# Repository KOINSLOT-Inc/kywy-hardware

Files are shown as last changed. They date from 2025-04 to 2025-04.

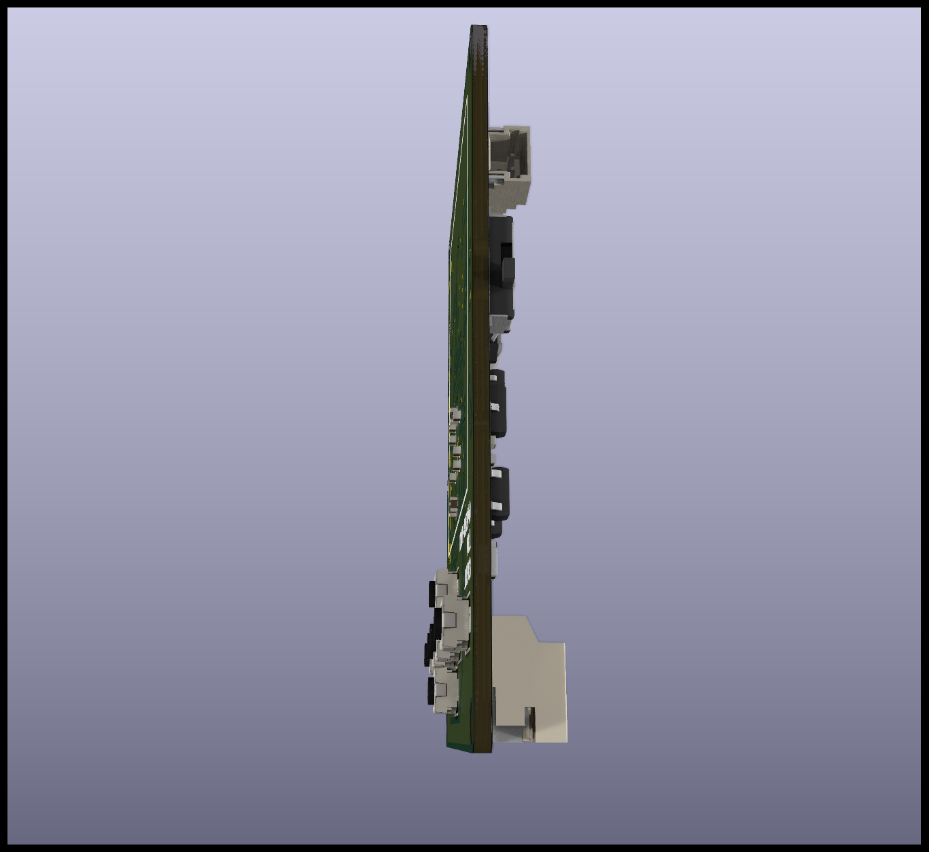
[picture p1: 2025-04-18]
PCB/Renders/Rotation/Kywy Micro Rotation 10.png

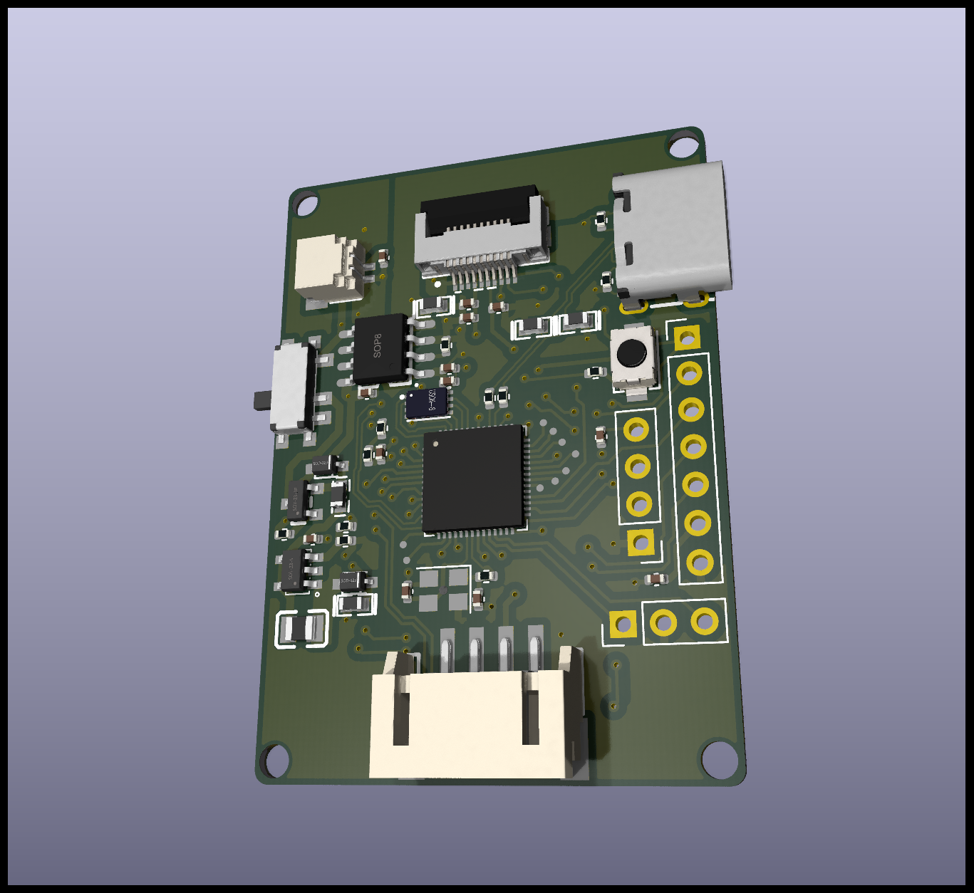
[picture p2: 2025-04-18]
PCB/Renders/Rotation/Kywy Micro Rotation 21.png

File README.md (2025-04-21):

<p align='center'>
  
  &nbsp;
  
  &nbsp;
  <a href="https://kywy.io/"><img alt="Website" src="https://img.shields.io/badge/KYWY.io-AAAAAA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" /></a>
  &nbsp;
  
</p>
<br />

# Kywy-Micro
 A handheld device for gaming
 
This repo contains all of the files you need to build a kywy pcb and 3d printed case

buy a kywy at [kywy.io](https://kywy.io)

Find our C++ and Rust libraries here: https://github.com/KOINSLOT-Inc

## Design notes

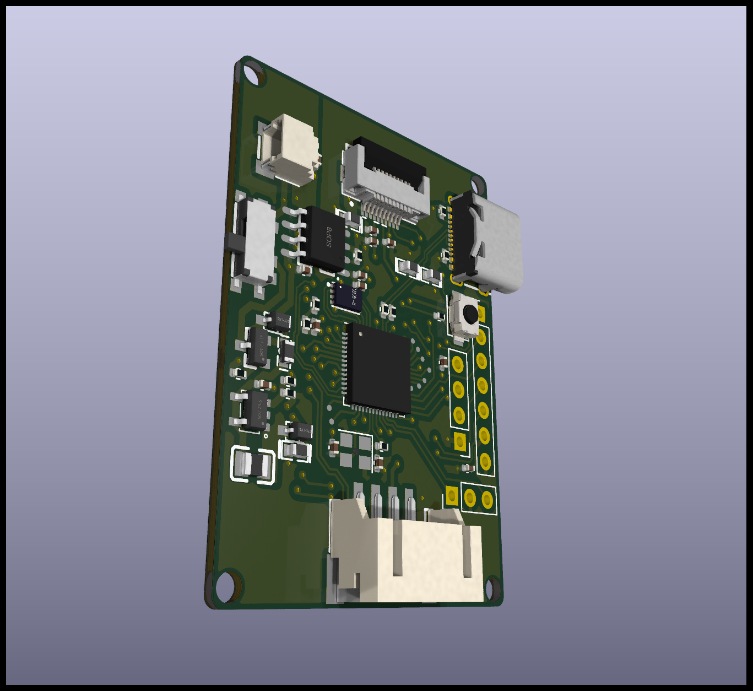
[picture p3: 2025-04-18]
PCB/Renders/Rotation/Kywy Micro Rotation 15.png

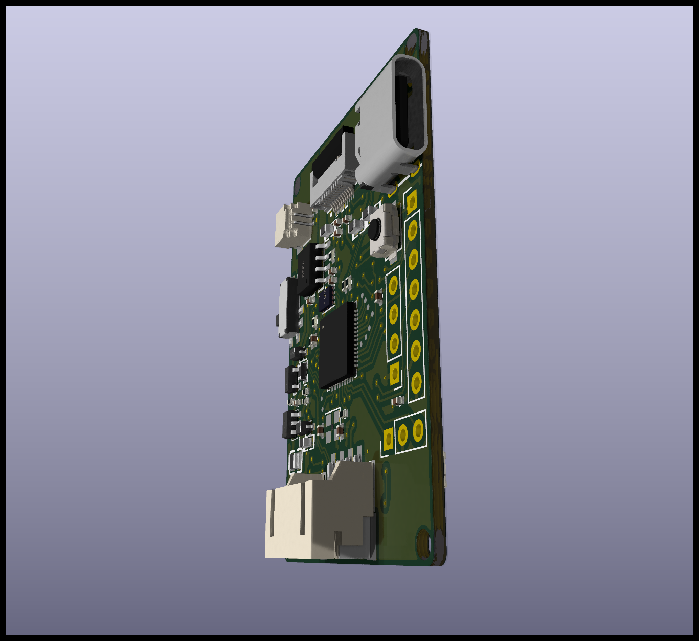
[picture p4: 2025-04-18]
PCB/Renders/Rotation/Kywy Micro Rotation 26.png

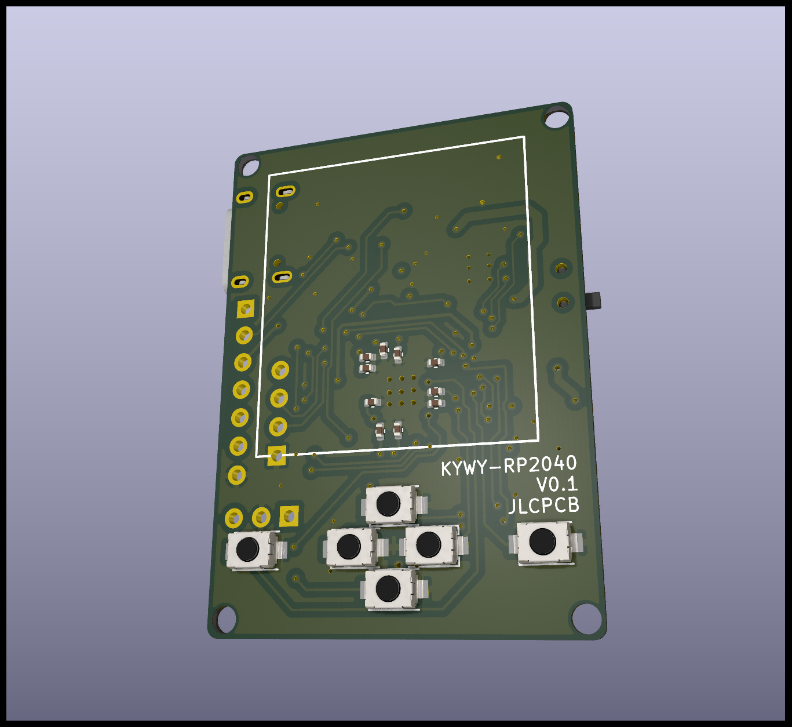
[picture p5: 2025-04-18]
PCB/Renders/Rotation/Kywy Micro Rotation 03.png

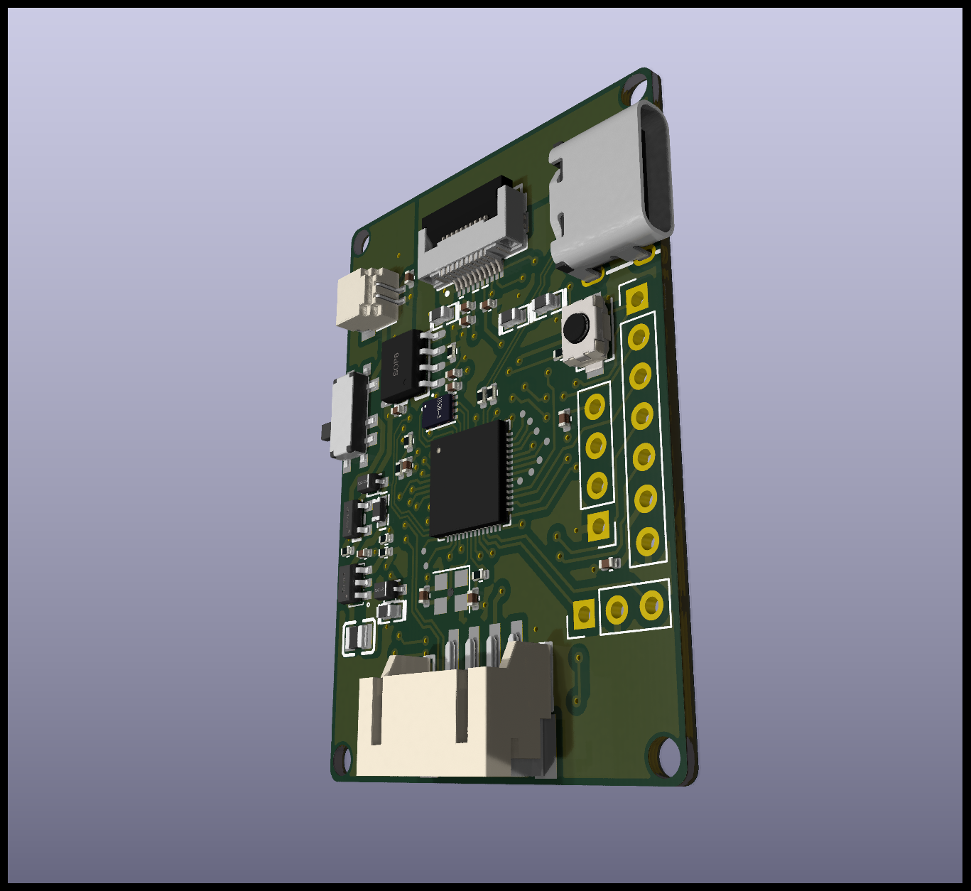
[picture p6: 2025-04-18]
PCB/Renders/Rotation/Kywy Micro Rotation 24.png

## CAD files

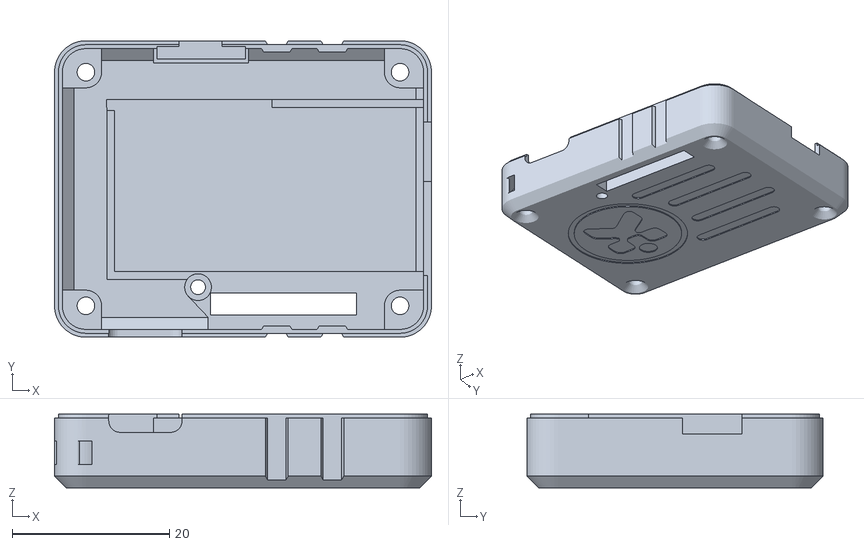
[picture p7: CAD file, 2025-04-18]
KYWY Case/Back.obj
48.0 x 37.8 x 9.40

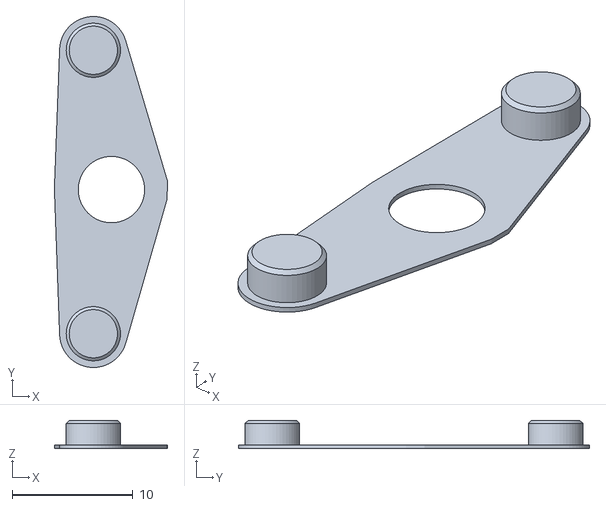
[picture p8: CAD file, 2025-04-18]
KYWY Case/Side Buttons.obj
9.39 x 29.1 x 2.35

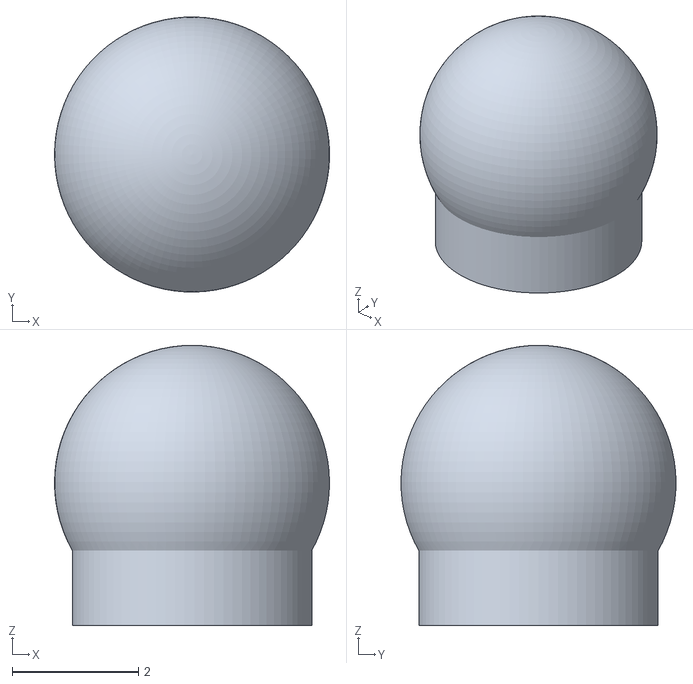
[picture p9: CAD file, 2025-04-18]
KYWY Case/Joystick.obj
4.35 x 4.35 x 4.44

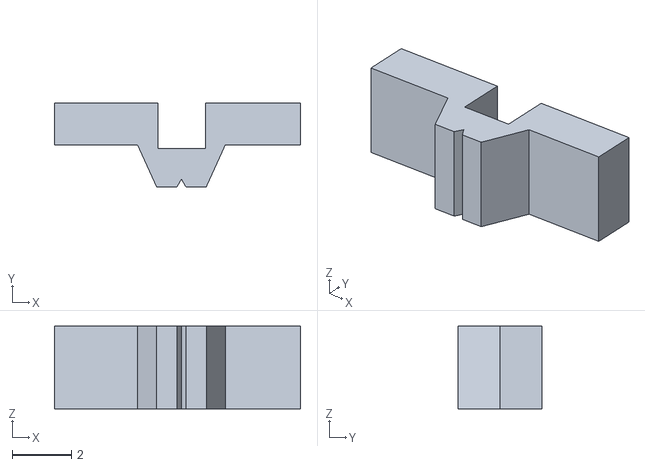
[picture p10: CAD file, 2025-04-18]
KYWY Case/Power Slider.obj
8.30 x 2.82 x 2.80

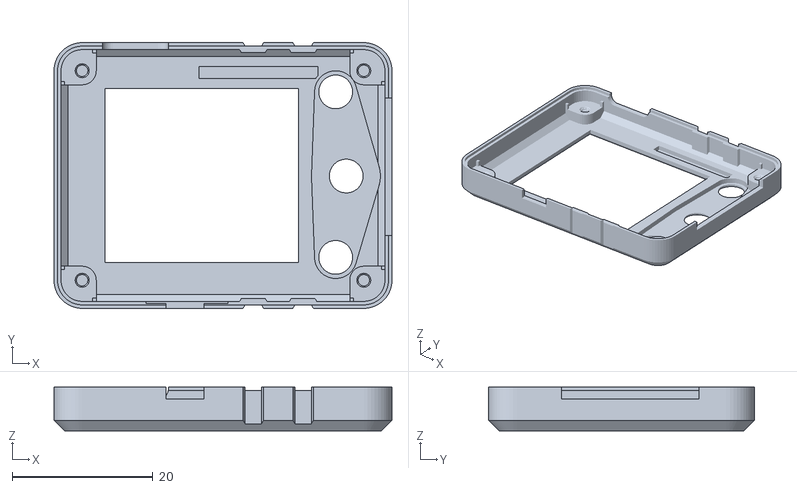
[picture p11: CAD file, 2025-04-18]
KYWY Case/Front.obj
48.0 x 37.8 x 6.20

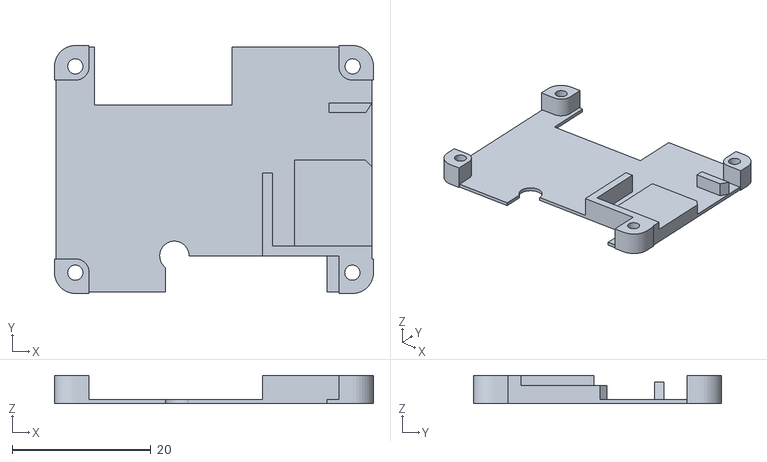
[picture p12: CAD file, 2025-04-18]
KYWY Case/Separator.obj
46.0 x 35.8 x 4.10

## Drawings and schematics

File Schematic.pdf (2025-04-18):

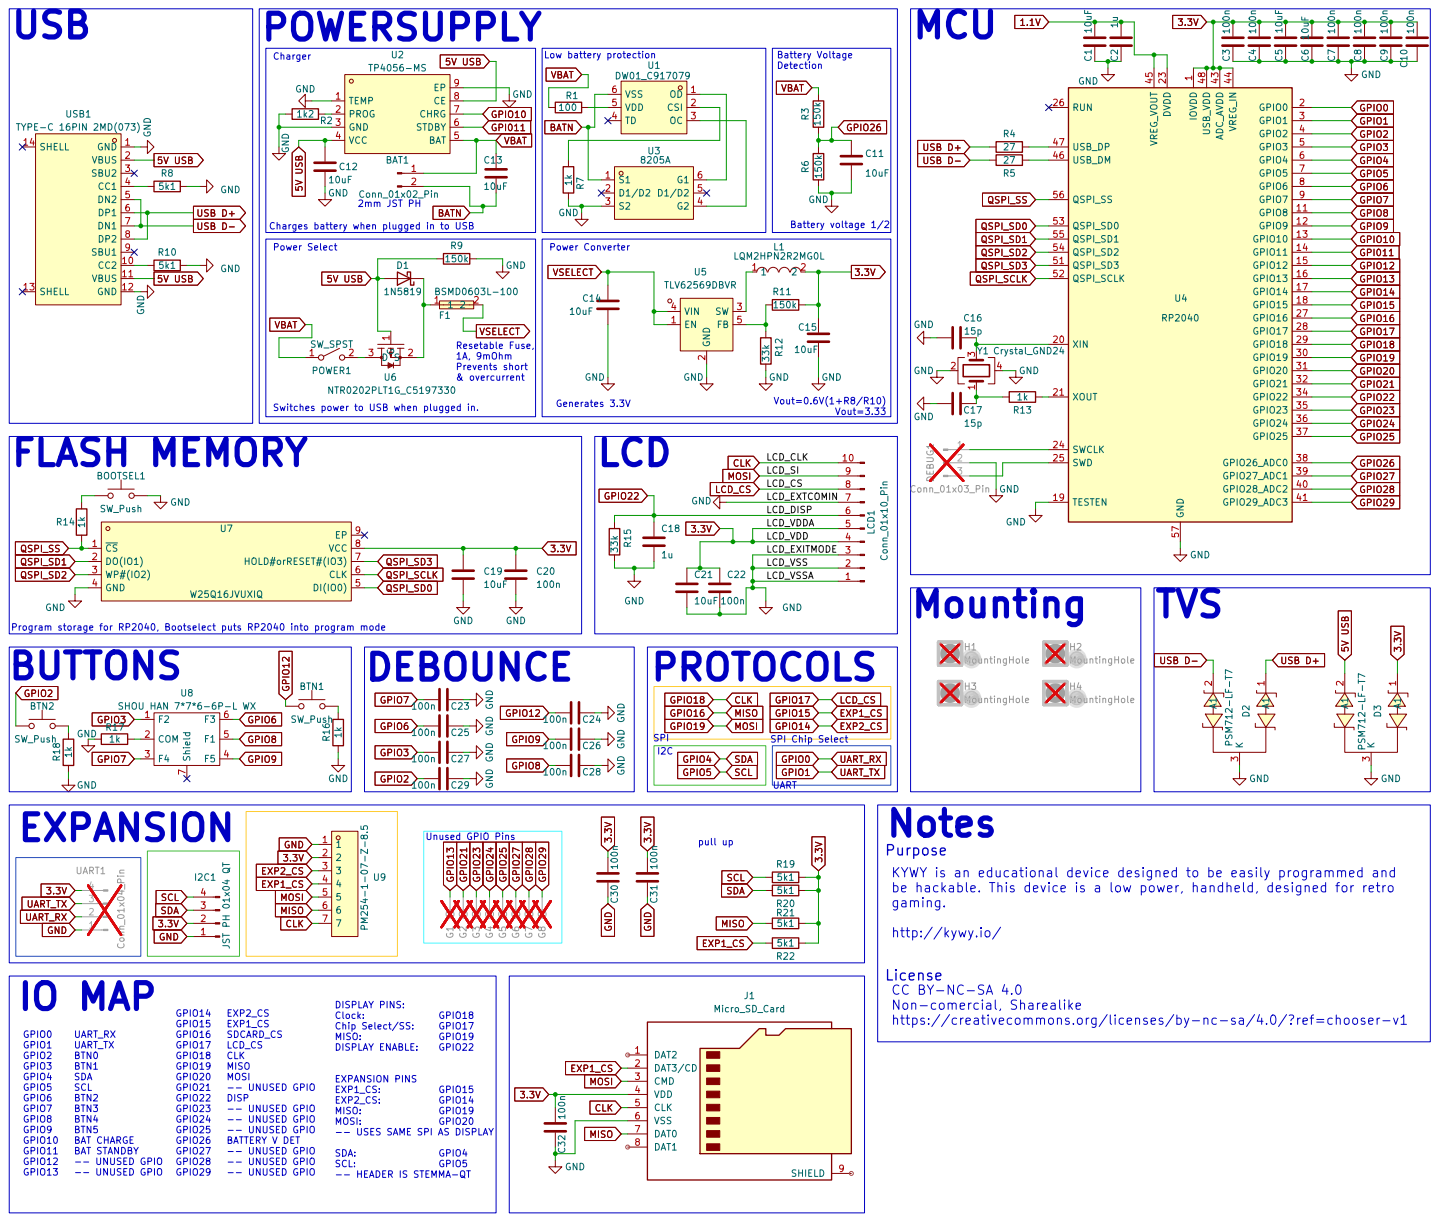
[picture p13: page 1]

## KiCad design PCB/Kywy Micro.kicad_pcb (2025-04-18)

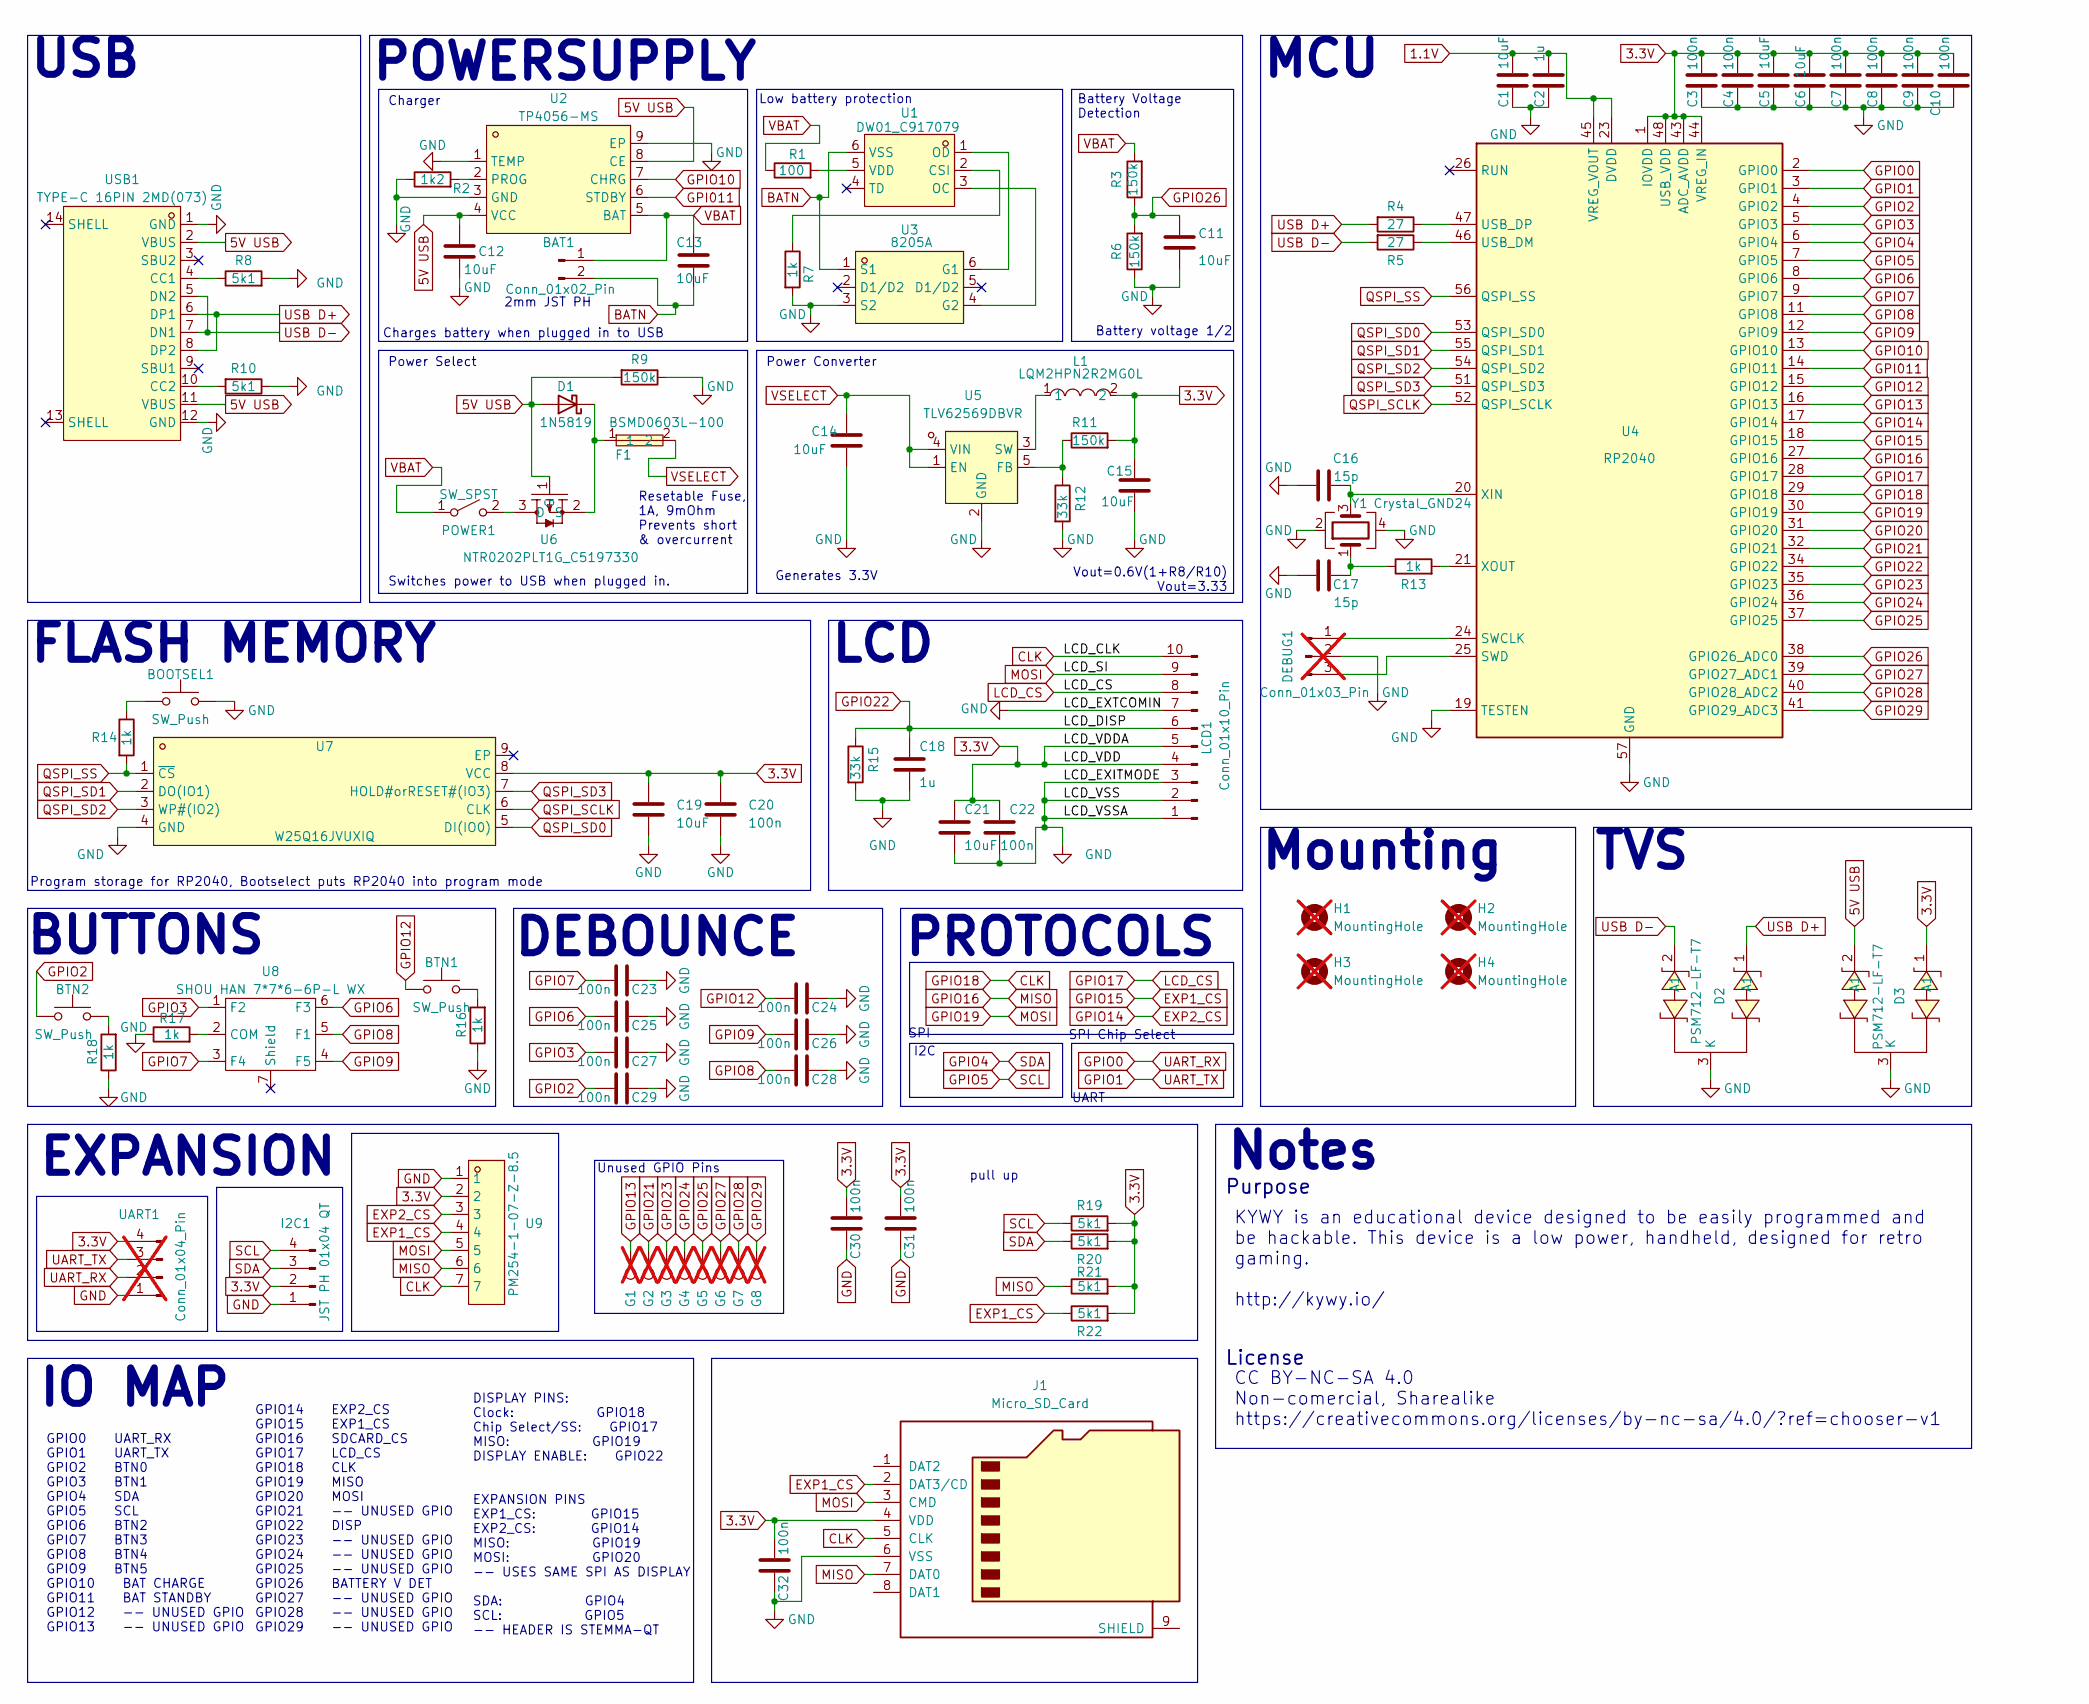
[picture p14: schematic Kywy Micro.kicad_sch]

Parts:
BAT1: Conn_01x02_Pin; CONN-TH_2P-P2.00_HX-2.0MM-2P-ZZ; JLCPCB Part #（optional） C5368724
BOOTSEL1: SW_Push; SW-SMD_L3.9-W3.0-P4.45; JLCPCB Part #（optional） C720477
BTN1, BTN2: SW_Push; SW-SMD_L3.9-W3.0-P4.45; JLCPCB Part #（optional） C720477
C1, C5, C6, C11, C12, C13, C14, C15, C19, C21: 10uF; C_0402_1005Metric; JLCPCB Part #（optional） C15525
C2, C18: 1u; C_0402_1005Metric; JLCPCB Part #（optional） C52923
C3, C4, C7, C8, C9, C10, C20, C22, C23, C24, C25, C26, C27, C28, C29, C30, C31, C32: 100n; C_0402_1005Metric; JLCPCB Part #（optional） C1525
C16, C17: 15p; C_0402_1005Metric; JLCPCB Part #（optional） C1548
D1: 1N5819; SOD-323_L1.8-W1.3-LS2.5-RD; JLCPCB Part #（optional） C191023
D2, D3: PSM712-LF-T7; SOT-23-3_L3.0-W1.7-P0.95-LS2.9-BR; LCSC Part C32677
DEBUG1: Conn_01x03_Pin; PinHeader_1x03_P2.54mm_Vertical; JLCPCB Part #（optional） DNP; not fitted
F1: BSMD0603L-100; F0603; JLCPCB Part #（optional） C2757929
G1, G2, G3, G4, G5, G6, G7, G8: TestPoint; Small Test Pad; JLCPCB Part #（optional） DNP; not fitted
H1, H2, H3, H4: MountingHole; MountingHole_2.2mm_M2; JLCPCB Part #（optional） DNP; not fitted
I2C1: JST PH 01x04 QT; CONN-SMD_4P-P1.00_MEGASTAR_ZX-SH1.0-4PWT; JLCPCB Part #（optional） C7430446
J1: Micro_SD_Card; TF-SMD_TF-123-ARP9H15; JLCPCB Part #（optional） C2982547
L1: LQM2HPN2R2MG0L; L1008; LCSC Part C86092
LCD1: Conn_01x10_Pin; FPC-SMD_P0.5-10P_FGS-XJ-H2.0; JLCPCB Part #（optional） C262659
POWER1: SW_SPST; SW-SMD_3P-P1.50_L2.7-W6.6; JLCPCB Part #（optional） C963206
R1: 100; R_0402_1005Metric; JLCPCB Part #（optional） C144045
R2: 1k2; R_0402_1005Metric; JLCPCB Part #（optional） C25862
R3, R6, R9, R11: 150k; R_0402_1005Metric; JLCPCB Part #（optional） C25755
R4, R5: 27; R_0402_1005Metric; JLCPCB Part #（optional） C25100
R7, R13, R14, R16, R17, R18: 1k; R_0402_1005Metric; JLCPCB Part #（optional） C11702
R8, R10, R19, R20, R21, R22: 5k1; R_0402_1005Metric; JLCPCB Part #（optional） C25905
R12, R15: 33k; R_0402_1005Metric; JLCPCB Part #（optional） C25779
U1: DW01_C917079; SOT-23-6_L2.9-W1.6-P0.95-LS2.8-BL; LCSC Part C917079
U2: TP4056-MS; SOP-8_L4.9-W3.9-P1.27-LS6.0-TL-EP; JLCPCB Part #（optional） C7473158
U3: 8205A; SOT-23-6_L2.9-W1.6-P0.95-LS2.8-BR; LCSC Part C2762931
U4: RP2040; QFN-56-1EP_7x7mm_P0.4mm_EP3.2x3.2mm; JLCPCB Part #（optional） C2040
U5: TLV62569DBVR; SOT-23-5_L3.0-W1.7-P0.95-LS2.8-BR; LCSC Part C141836
U6: NTR0202PLT1G_C5197330; SOT-23_L2.9-W1.3-P1.90-LS2.4-BR; JLCPCB Part #（optional） C5224173
U7: W25Q16JVUXIQ; USON-8_L3.0-W2.0-P0.50-BL-EP; JLCPCB Part #（optional） C2843335
U8: SHOU HAN 7*7*6-6P-L WX; SW-SMD_6P-L7.0-W7.0-P1.40-LS7.4; JLCPCB Part #（optional） C2858288
U9: PM254-1-07-Z-8.5; HDR-TH_7P-P2.54-V-F; LCSC Part C2897370
UART1: Conn_01x04_Pin; PinHeader_1x04_P2.54mm_Vertical; JLCPCB Part #（optional） DNP; not fitted
USB1: TYPE-C 16PIN 2MD(073); USB-C-SMD_TYPE-C-6PIN-2MD-073; JLCPCB Part #（optional） C2765186
Y1: Crystal_GND24; CRYSTAL-SMD_4P-L3.2-W2.5-BL; JLCPCB Part #（optional） C9002

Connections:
1.1V: C1.2, C2.2, U4.23 (DVDD), U4.45 (VREG_VOUT), U4.50 (DVDD)
3.3V: C3.2, C4.2, C5.2, C6.2, C7.2, C8.2, C9.2, C10.2, C15.1, C19.1, C20.1, C21.1, C22.1, C30.2, C31.2, C32.2, D3.1 (A1), I2C1.2, J1.4 (VDD), L1.2, LCD1.4, LCD1.5, R11.2, R19.2, R20.2, R21.2, R22.2, U4.1 (IOVDD), U4.10 (IOVDD), U4.22 (IOVDD), U4.33 (IOVDD), U4.42 (IOVDD), U4.43 (ADC_AVDD), U4.44 (VREG_IN), U4.48 (USB_VDD), U4.49 (IOVDD), U7.8 (VCC), U9.2, UART1.4
5V USB: C12.1, D1.2 (A), D3.2 (A1), R9.2, U2.4 (VCC), U2.8 (CE), U6.1 (G), USB1.2 (VBUS), USB1.11 (VBUS)
BATN: BAT1.2, C13.2, U1.6 (VSS), U3.1 (S1)
CLK: J1.5 (CLK), LCD1.10, U4.29 (GPIO18), U9.7
EXP1_CS: J1.2 (DAT3/CD), R22.1, U4.18 (GPIO15), U9.4
EXP2_CS: U4.17 (GPIO14), U9.3
GND: BOOTSEL1.2, C1.1, C2.1, C3.1, C4.1, C5.1, C6.1, C7.1, C8.1, C9.1, C10.1, C11.2, C12.2, C14.2, C15.2, C16.1, C17.1, C18.2, C19.2, C20.2, C21.2, C22.2, C23.1, C24.1, C25.1, C26.1, C27.1, C28.1, C29.1, C30.1, C31.1, C32.1, D2.3 (K), D3.3 (K), DEBUG1.2, I2C1.1, J1.6 (VSS), LCD1.1, LCD1.2, LCD1.3, LCD1.7, R2.1, R6.1, R7.2, R8.2, R9.1, R10.1, R12.2, R15.2, R16.1, R17.1, R18.1, U2.1 (TEMP), U2.3 (GND), U2.9 (EP), U3.3 (S2), U4.19 (TESTEN), U4.57 (GND), U5.2 (GND), U7.4 (GND), U9.1, UART1.1, USB1.1 (GND), USB1.12 (GND), Y1.2, Y1.4
GPI011: U2.6 (STDBY), U4.14 (GPIO11)
GPIO0: U4.2 (GPIO0), UART1.2
GPIO1: U4.3 (GPIO1), UART1.3
GPIO2: BTN2.1, C29.2, U4.4 (GPIO2)
GPIO3: C27.2, U4.5 (GPIO3), U8.1 (F2)
GPIO4: I2C1.3, R20.1, U4.6 (GPIO4)
GPIO5: I2C1.4, R19.1, U4.7 (GPIO5)
GPIO6: C25.2, U4.8 (GPIO6), U8.6 (F3)
GPIO7: C23.2, U4.9 (GPIO7), U8.3 (F4)
GPIO8: C28.2, U4.11 (GPIO8), U8.5 (F1)
GPIO9: C26.2, U4.12 (GPIO9), U8.4 (F5)
GPIO10: U2.7 (CHRG), U4.13 (GPIO10)
GPIO12: BTN1.1, C24.2, U4.15 (GPIO12)
GPIO13: G1.1, U4.16 (GPIO13)
GPIO16: J1.7 (DAT0), R21.1, U4.27 (GPIO16), U9.6
GPIO17: LCD1.8, U4.28 (GPIO17)
GPIO19: J1.3 (CMD), LCD1.9, U4.30 (GPIO19), U9.5
GPIO20: U4.31 (GPIO20)
GPIO21: G2.1, U4.32 (GPIO21)
GPIO22: C18.1, LCD1.6, R15.1, U4.34 (GPIO22)
GPIO23: G3.1, U4.35 (GPIO23)
GPIO24: G4.1, U4.36 (GPIO24)
GPIO25: G5.1, U4.37 (GPIO25)
GPIO26: C11.1, R3.1, R6.2, U4.38 (GPIO26_ADC0)
GPIO27: G6.1, U4.39 (GPIO27_ADC1)
GPIO28: G7.1, U4.40 (GPIO28_ADC2)
GPIO29: G8.1, U4.41 (GPIO29_ADC3)
unnamed: BOOTSEL1.1, R14.1
unnamed: BTN1.2, R16.2
unnamed: BTN2.2, R18.2
unnamed: C17.2, R13.1, Y1.1
unnamed: D1.1 (K), F1.1, U6.2 (S)
unnamed: DEBUG1.1, U4.24 (SWCLK)
unnamed: DEBUG1.3, U4.25 (SWD)
unnamed: POWER1.2 (B), U6.3 (D)
unnamed: R7.1, U1.2 (CSI)
unnamed: U1.3 (OC), U3.4 (G2)
unnamed: U1.1 (OD), U3.6 (G1)
unnamed: R1.2, U1.5 (VDD)
unnamed: R2.2, U2.2 (PROG)
unnamed: R5.1, U4.46 (USB_DM)
unnamed: R4.1, U4.47 (USB_DP)
unnamed: C16.2, U4.20 (XIN), Y1.3
unnamed: R13.2, U4.21 (XOUT)
unnamed: R11.1, R12.1, U5.5 (FB)
unnamed: L1.1, U5.3 (SW)
unnamed: R17.2, U8.2 (COM)
unnamed: R8.1, USB1.4 (CC1)
unnamed: R10.2, USB1.10 (CC2)
QSPI_SCLK: U4.52 (QSPI_SCLK), U7.6 (CLK)
QSPI_SD0: U4.53 (QSPI_SD0), U7.5 (DI(IO0))
QSPI_SD1: U4.55 (QSPI_SD1), U7.2 (DO(IO1))
QSPI_SD2: U4.54 (QSPI_SD2), U7.3 (WP#(IO2))
QSPI_SD3: U4.51 (QSPI_SD3), U7.7 (HOLD#orRESET#(IO3))
QSPI_SS: R14.2, U4.56 (QSPI_SS), U7.1 (~CS)
USB D+: D2.1 (A1), R4.2, USB1.6 (DP1), USB1.8 (DP2)
USB D-: D2.2 (A1), R5.2, USB1.5 (DN2), USB1.7 (DN1)
VBAT: BAT1.1, C13.1, POWER1.1 (A), R1.1, R3.2, U2.5 (BAT)
VSELECT: C14.1, F1.2, U5.1 (EN), U5.4 (VIN)

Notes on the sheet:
Power Select
Notes
SPI Chip Select
Low battery protection
Battery voltage 1/2
EXPANSION
Charger
DISPLAY PINS: Clock: GPIO18 Chip Select/SS: GPIO17 MISO: GPIO19 DISPLAY ENABLE: GPIO22 EXPANSION PINS EXP1_CS: GPIO15 EXP2_CS: GPIO14 MISO: GPIO19 MOSI: GPIO20 -- USES SAME SPI AS DISPLAY SDA: GPIO4 SCL: GPIO5 -- HEADER IS STEMMA-QT
Vout=0.6V(1+R8/R10) Vout=3.33
pull up
CC BY-NC-SA 4.0 Non-comercial, Sharealike https://creativecommons.org/licenses/by-nc-sa/4.0/?ref=chooser-v1
PROTOCOLS
2mm JST PH
License
Battery Voltage Detection
Generates 3.3V
I2C
Switches power to USB when plugged in.
SPI
FLASH MEMORY
UART
TVS
Program storage for RP2040, Bootselect puts RP2040 into program mode
Unused GPIO Pins
IO MAP
MCU
GPIO0 UART_RX GPIO1 UART_TX GPIO2 BTN0 GPIO3 BTN1 GPIO4 SDA GPIO5 SCL GPIO6 BTN2 GPIO7 BTN3 GPIO8 BTN4 GPIO9 BTN5 GPIO10 BAT CHARGE GPIO11 BAT STANDBY GPIO12 -- UNUSED GPIO GPIO13 -- UNUSED GPIO
Mounting
KYWY is an educational device designed to be easily programmed and be hackable. This device is a low power, handheld, designed for retro gaming. http://kywy.io/
Resetable Fuse, 1A, 9mOhm Prevents short & overcurrent
GPIO14 EXP2_CS GPIO15 EXP1_CS GPIO16 SDCARD_CS GPIO17 LCD_CS GPIO18 CLK GPIO19 MISO GPIO20 MOSI GPIO21 -- UNUSED GPIO GPIO22 DISP GPIO23 -- UNUSED GPIO GPIO24 -- UNUSED GPIO GPIO25 -- UNUSED GPIO GPIO26 BATTERY V DET GPIO27 -- UNUSED GPIO GPIO28 -- UNUSED GPIO GPIO29 -- UNUSED GPIO
Purpose
POWERSUPPLY
DEBOUNCE
Power Converter
BUTTONS
LCD
Charges battery when plugged in to USB
USB

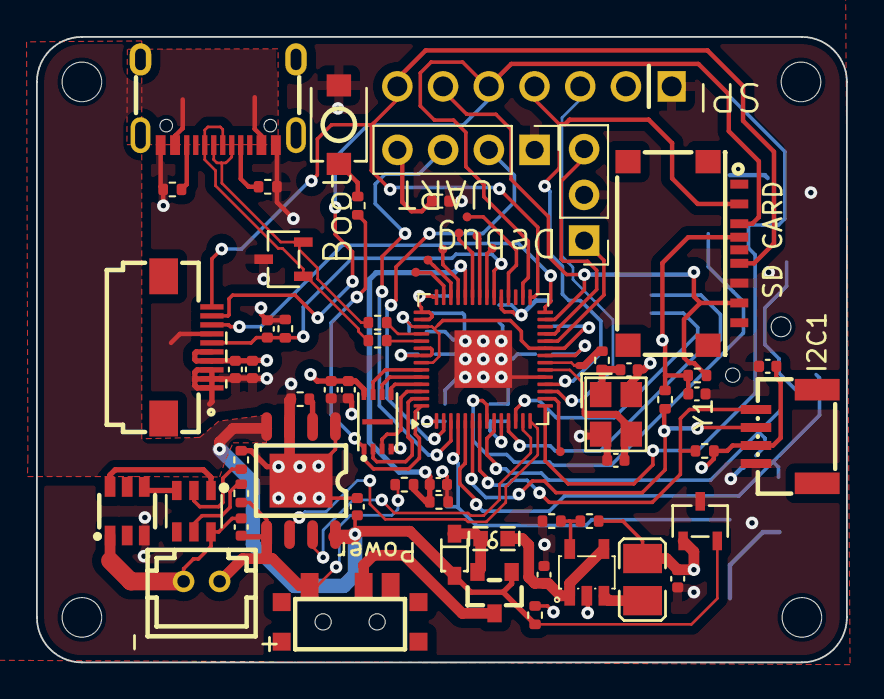
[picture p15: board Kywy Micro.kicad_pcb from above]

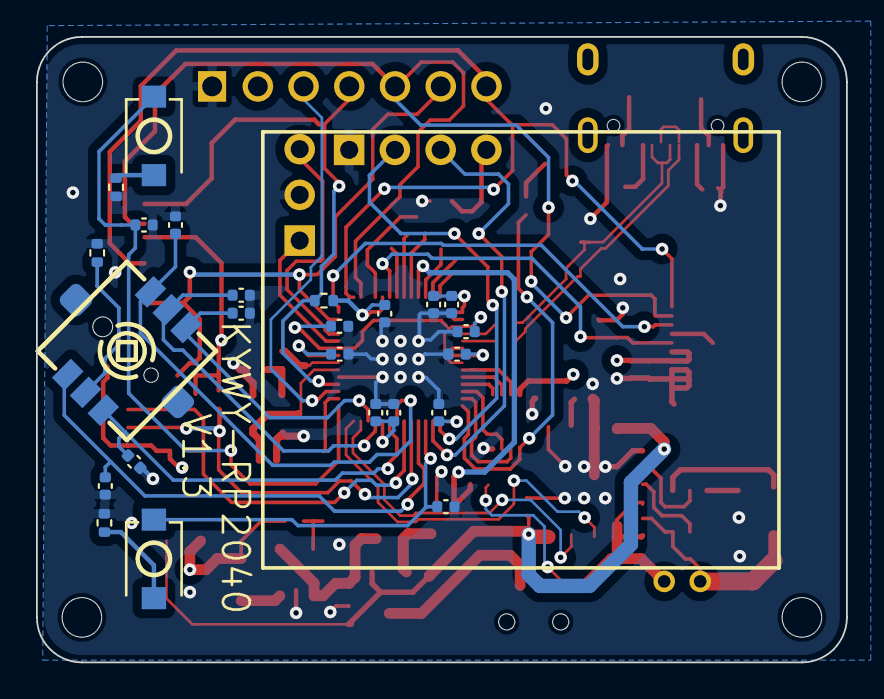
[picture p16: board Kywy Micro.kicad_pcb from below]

Board: 4 copper layers, 45.0 x 34.8 mm, 92 parts (24 on the bottom side), 66 nets.
